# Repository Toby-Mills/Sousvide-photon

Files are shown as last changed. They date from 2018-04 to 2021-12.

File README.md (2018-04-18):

# photon

A Particle project named photon

## Welcome to your project!

Every new Particle project is composed of 3 important elements that you'll see have been created in your project directory for photon.

#### ```/src``` folder:  
This is the source folder that contains the firmware files for your project. It should *not* be renamed. 
Anything that is in this folder when you compile your project will be sent to our compile service and compiled into a firmware binary for the Particle device that you have targeted.

If your application contains multiple files, they should all be included in the `src` folder. If your firmware depends on Particle libraries, those dependencies are specified in the `project.properties` file referenced below.

#### ```.ino``` file:
This file is the firmware that will run as the primary application on your Particle device. It contains a `setup()` and `loop()` function, and can be written in Wiring or C/C++. For more information about using the Particle firmware API to create firmware for your Particle device, refer to the [Firmware Reference](https://docs.particle.io/reference/firmware/) section of the Particle documentation.

#### ```project.properties``` file:  
This is the file that specifies the name and version number of the libraries that your project depends on. Dependencies are added automatically to your `project.properties` file when you add a library to a project using the `particle library add` command in the CLI or add a library in the Desktop IDE.

## Adding additional files to your project

#### Projects with multiple sources
If you would like add additional files to your application, they should be added to the `/src` folder. All files in the `/src` folder will be sent to the Particle Cloud to produce a compiled binary.

#### Projects with external libraries
If your project includes a library that has not been registered in the Particle libraries system, you should create a new folder named `/lib/<libraryname>/src` under `/<project dir>` and add the `.h` and `.cpp` files for your library there. All contents of the `/lib` folder and subfolders will also be sent to the Cloud for compilation.

## Compiling your project

When you're ready to compile your project, make sure you have the correct Particle device target selected and run `particle compile <platform>` in the CLI or click the Compile button in the Desktop IDE. The following files in your project folder will be sent to the compile service:

- Everything in the `/src` folder, including your `.ino` application file
- The `project.properties` file for your project
- Any libraries stored under `lib/<libraryname>/src`

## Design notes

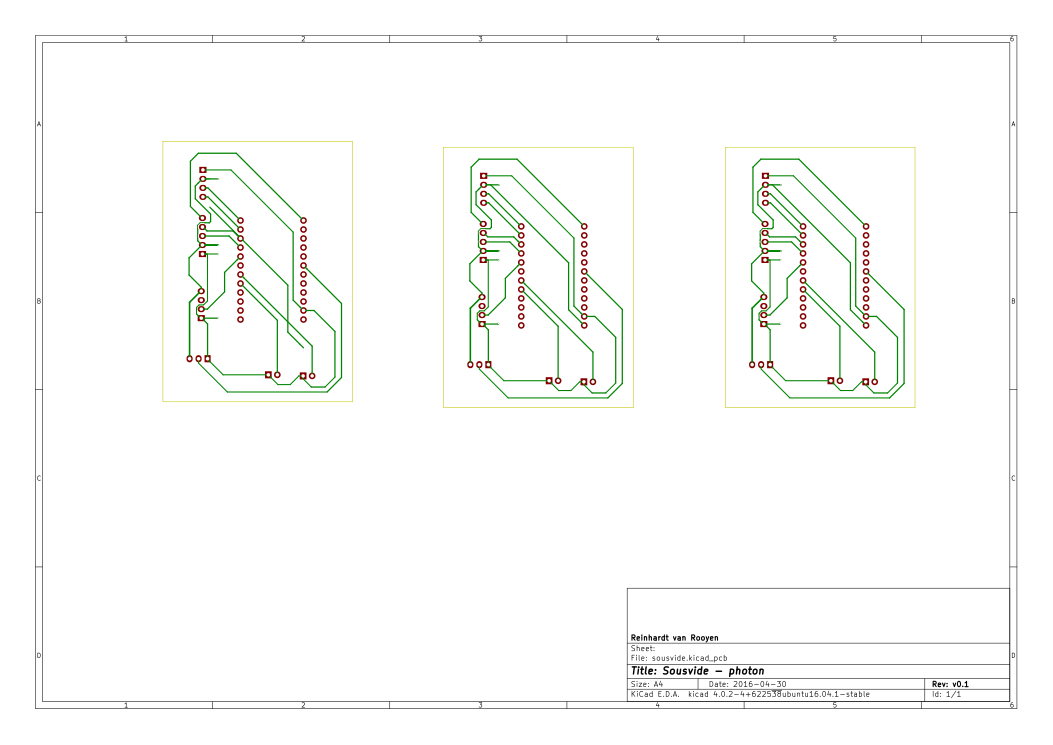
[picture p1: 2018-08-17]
hardware/sousvide-B.Cu-3.png

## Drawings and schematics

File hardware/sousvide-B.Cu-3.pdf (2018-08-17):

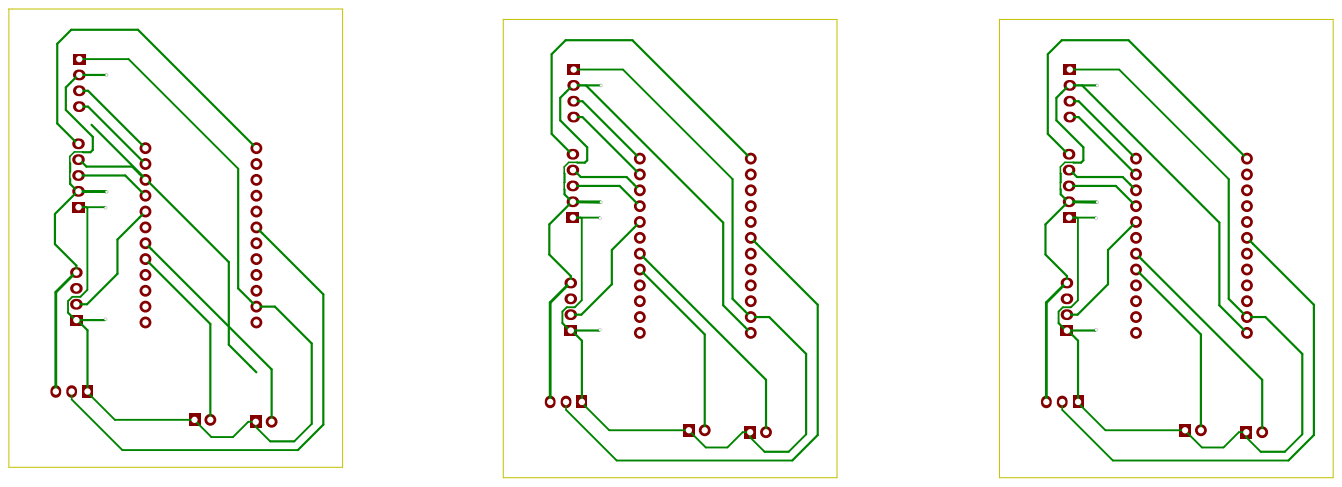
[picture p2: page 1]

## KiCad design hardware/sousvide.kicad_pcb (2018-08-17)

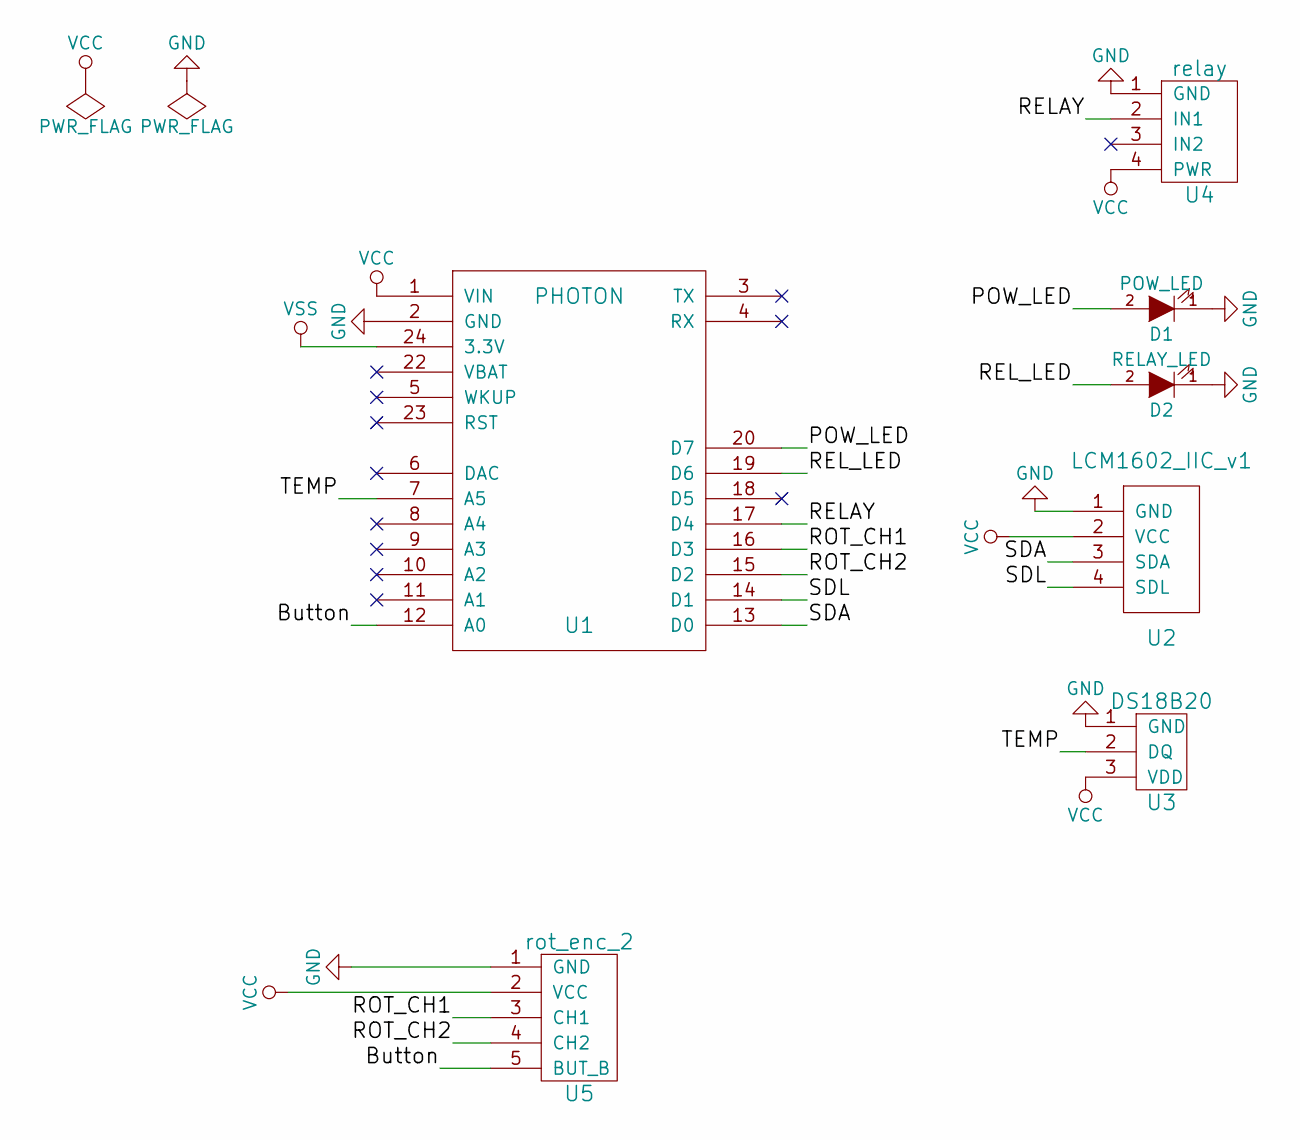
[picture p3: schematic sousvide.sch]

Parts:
D1: POW_LED; LED-5MM
D2: RELAY_LED; LED-5MM
U1: PHOTON; photon
U2: LCM1602_IIC_v1; Pin_Header_Straight_1x04
U3: DS18B20; Pin_Header_Straight_1x03
U4: relay; Pin_Header_Straight_1x04
U5: rot_enc_2; Pin_Header_Straight_1x05

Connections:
/Button: U1.12 (A0), U5.5 (BUT_B)
/POW_LED: D1.2 (A), U1.20 (D7)
/RELAY: U1.17 (D4), U4.2 (IN1)
/REL_LED: D2.2 (A), U1.19 (D6)
/ROT_CH1: U1.16 (D3), U5.3 (CH1)
/ROT_CH2: U1.15 (D2), U5.4 (CH2)
/SDA: U1.13 (D0), U2.3 (SDA)
/SDL: U1.14 (D1), U2.4 (SDL)
/TEMP: U1.7 (A5), U3.2 (DQ)
GND: D1.1 (K), D2.1 (K), U1.2 (GND), U2.1 (GND), U3.1 (GND), U4.1 (GND), U5.1 (GND)
VCC: U1.1 (VIN), U2.2 (VCC), U3.3 (VDD), U4.4 (PWR), U5.2 (VCC)
VSS: U1.24 (3.3V)

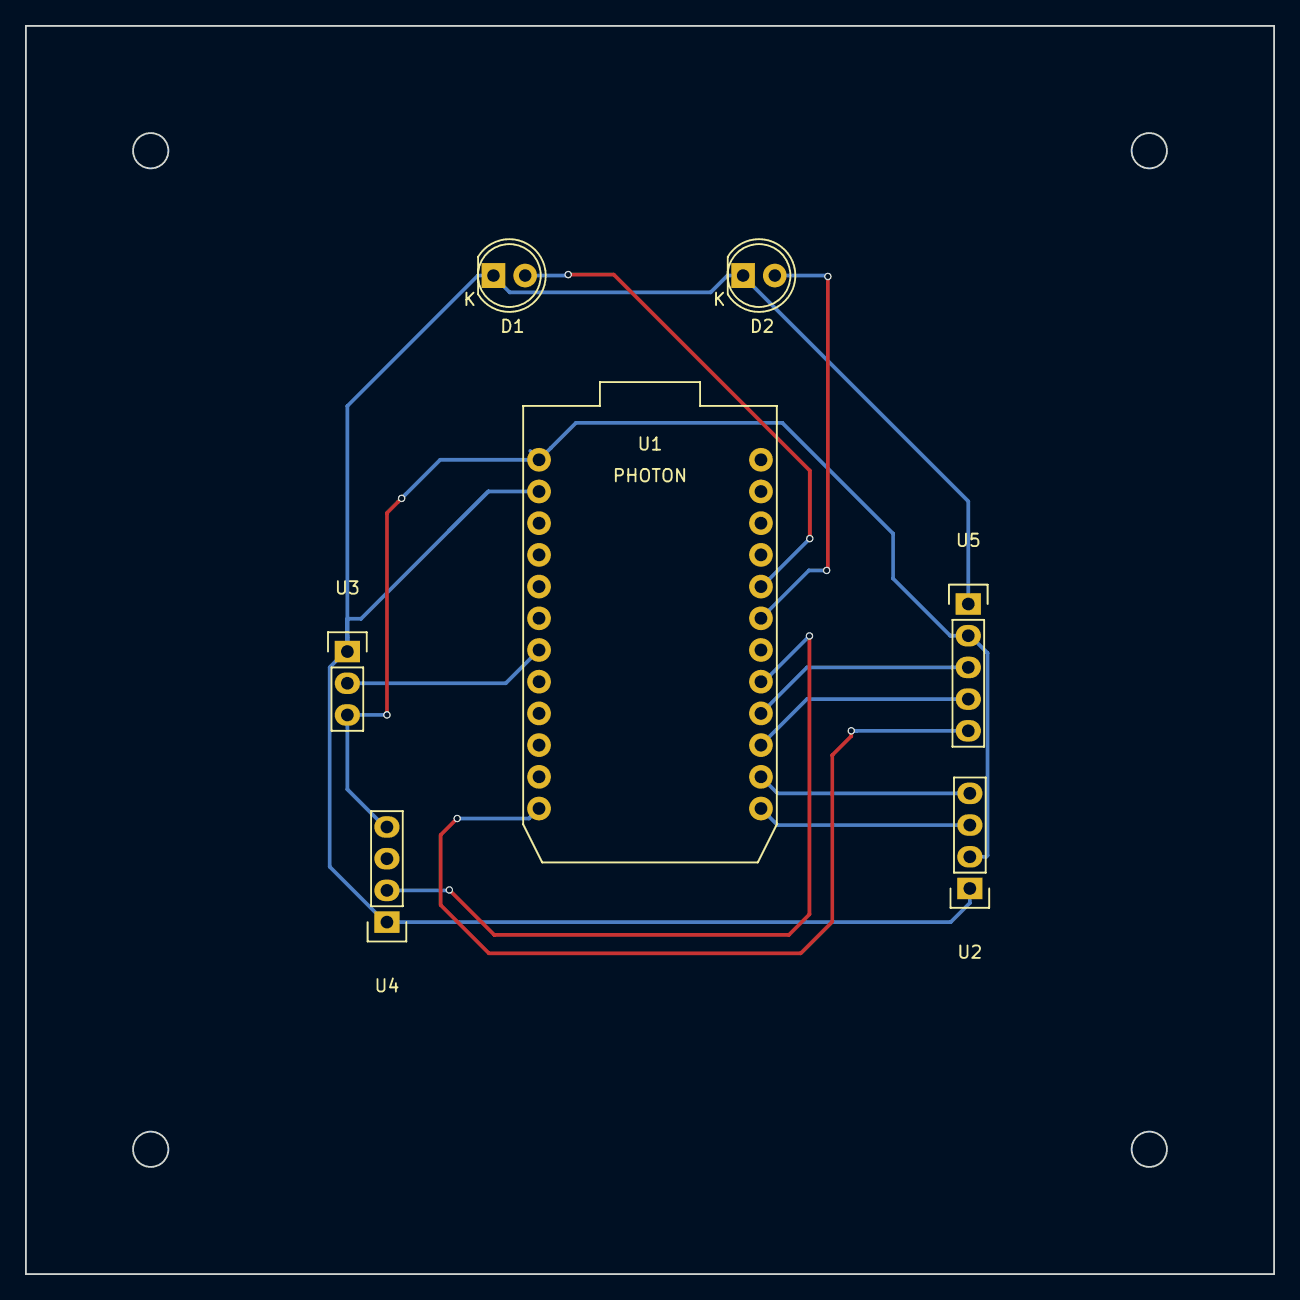
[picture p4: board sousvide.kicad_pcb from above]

Board: 2 copper layers, 100.0 x 100.0 mm, 7 parts (0 on the bottom side), 11 nets.

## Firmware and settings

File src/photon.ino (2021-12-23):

//--------------------------------------------------------------
// Included libraries
//--------------------------------------------------------------
#include "config.h" //add your own config.h with: char const blynkToken[] = "your-blynk-token-here"
#include "OneWire.h"
#include "spark-dallas-temperature/spark-dallas-temperature.h"
#include "LiquidCrystal_I2C_Spark.h"
#include <math.h>
#include <string.h>
#include <Encoder.h>
#include "MQTT.h"

//--------------------------------------------------------------
// Variables
//--------------------------------------------------------------
SYSTEM_THREAD(ENABLED); //enables system functions to happen in a separate thread from the application setup and loop
//this includes connecting to the network and the cloud

char *sourceCode = "https://github.com/Toby-Mills/Sousvide-photon";

int defaultTargetTemperature = 60;
double targetTemperature;
double currentTemperature = 0; //current temperature

char *messageCurrentTemp = "Current";
char *messageTargetTemp = "Target";
char *messageSetTemp = "Set Target";

unsigned long lastSensorReading = 0; //time of last sensor reading
unsigned long sensorReadingDelay = 1000; //minimum milliseconds between processing successive temperature readings

unsigned long lastRelayCommand = 0; //time of last command to relay
unsigned long relayCommandDelay = 5000; //minimum milliseconds between succesive commands to relay

unsigned long lastScreenRedraw = 0; //time of last screen redraw
unsigned long screenRedrawDelay = 600000; //minimum milliseconds between successive redraws of screen

long encoderNewPosition = -999;
long encoderOldPosition  = -999;

int buttonReading = 0;
bool buttonClick = false;

bool setTempMode = false;
int newTargetTemp =  0;

bool timerStarted = false;
bool timerEnded = false;
unsigned long timerLength = 0;
unsigned long timerStartTime = 0;
unsigned long lastTimerUpdate = 0; //time of last timer update
unsigned long timerUpdateDelay = 1000; //minimum milliseconds between succesive timer updates

unsigned long lastStatusPublish = 0; //time of last time the status was published
unsigned long StatusPublishDelay = 10000; //minimum milliseconds between publishing status updates
//--------------------------------------------------------------
//Pin declarations
//--------------------------------------------------------------
int ONE_WIRE_BUS = A5;
int relayPin = D4;
int encoderPin1 = D3;
int encoderPin2 = D2;
int ledPowerPin = D7;
int ledRelayPin = D6;
int buttonPin = A0;

//--------------------------------------------------------------
// MQTT
//--------------------------------------------------------------
bool mqttConnected = false;
byte mqttServer[] = {192, 168, 68, 135};
MQTT mqttClient(mqttServer, 1883, mqttCallback);
char *mqttTopic_cmnd_set_target = "cmnd/sous_vide/target";
char *mqttTopic_stat = "stat/sous_vide";
// char *mqttTopic_cmnd_start_timer = "cmnd/sous_vide/timer";
// char *mqttTopic_cmnd_stop = "cmnd/sous_vide/stop";

//--------------------------------------------------------------
// Initialize libraries
//--------------------------------------------------------------
LiquidCrystal_I2C *lcd;
 // Setup a oneWire instance to communicate with any OneWire devices
OneWire oneWire(ONE_WIRE_BUS);
// Pass our oneWire reference to Dallas Temperature.
DallasTemperature sensors(&oneWire);
DeviceAddress thermometer1 = { 0x28, 0x94, 0xE2, 0xDF, 0x02, 0x00, 0x00, 0xFE };
Encoder encoder(encoderPin1, encoderPin2);

//--------------------------------------------------------------
// Setup
//--------------------------------------------------------------

// setup() runs once, when the device is first turned on.
void setup() {
  Particle.variable("sourceCode", sourceCode, STRING);
  Particle.variable("currentTemp", currentTemperature);
  Particle.variable("targetTemp", targetTemperature);
  Particle.function("setTemp", setDesiredTemperature_Cloud);
  Particle.variable("buttonRead", buttonReading);
  Particle.variable("buttonClick", buttonClick);
  Particle.function("setTimer", setTimer_Cloud);
  Particle.variable("timerLength", timerLength);

  // Set pin modes
  pinMode(ONE_WIRE_BUS, INPUT);
  pinMode(relayPin, OUTPUT);
  pinMode(ledPowerPin, OUTPUT);
  pinMode(ledRelayPin, OUTPUT);
  pinMode(buttonPin, INPUT_PULLDOWN);

  digitalWrite(ledPowerPin, HIGH);

  loadDesiredTemperature();

  //initialize the temperature sensor
  sensors.begin();
  // set the resolution to 10 bit (good enough?)
  sensors.setResolution(thermometer1, 12);

  // initialize the lcd
  initializeDisplay();

  //initialize rotary encoder
  encoderOldPosition = encoder.read();

}

//--------------------------------------------------------------
// Loop
//--------------------------------------------------------------
void loop() {

  if (!mqttClient.isConnected())
  {
    mqttConnected = false;
    mqttClient.connect("sousVide");
  }
  else
  {
    if (!mqttConnected)
    {
      mqttConnected = true;
      mqttClient.publish("stat/sousVide", "connected");
      Particle.publish("Log Event", "mqtt connected");
      mqttClient.subscribe(mqttTopic_cmnd_set_target);
      // mqttClient.subscribe(mqttTopic_cmnd_start);
      // mqttClient.subscribe(mqttTopic_cmnd_start_timer);
      // mqttClient.subscribe(mqttTopic_cmnd_stop);
    }
    mqttClient.loop();
  }

  if (buttonClicked()){
    if(setTempMode == false){
        newTargetTemp = targetTemperature;
        setTempMode = true;
        redrawScreen();
    }else{
      setDesiredTemperature(newTargetTemp);
      setTempMode = false;
      redrawScreen();
    }
  }

  if(setTempMode==true){
    int encoderDirection = readEncoderDirection();
    newTargetTemp = newTargetTemp + encoderDirection;
    writeScreenBottomValue(newTargetTemp);
  }

  //process a sensor reading if the minimum time has elapsed
  if ( millis() - lastSensorReading >= sensorReadingDelay) {
    float sensorTemperature;
    sensorTemperature = getSensorTemperature();
    if(sensorTemperature > -127){
      currentTemperature = sensorTemperature;
    }

    //record time of last sensor reading
    lastSensorReading = millis();

    //write the current temperature to the screen
    writeScreenTopValue(currentTemperature);
  }

  //publish a status update if needed
  if ( millis() - lastStatusPublish >= StatusPublishDelay) {
      char msg[50];
      sprintf(msg, "{\"currentTemp\": %0.2f, \"targetTemp\": %0.2f}", currentTemperature, targetTemperature);
      mqttClient.publish(mqttTopic_stat, msg);
      lastStatusPublish = millis();
  }

  switchRelay();
  updateTimer();

  //redraw the screen if the minimum time has elapsed
  if (( millis()  - lastScreenRedraw >= screenRedrawDelay) ||(lastScreenRedraw == 0)){
    redrawScreen();
    //record time of latest screen redraw
    lastScreenRedraw = millis();
  }
//end of loop
}

//---------------------------------------------------------------
// Functions
//---------------------------------------------------------------

void publishMessage(String name, String message, int value)
{
  char msg[50];
  sprintf(msg, message.c_str(), value);
  Particle.publish(name, msg, 600, PRIVATE);
}

void updateTimer(){
  unsigned long timeRemaining;

  if (( millis() - lastTimerUpdate >= timerUpdateDelay) || (lastTimerUpdate == 0)) {
    if(timerLength > 0){
      if(timerStarted == false){
        if(currentTemperature > targetTemperature){
          timerStarted = true;
          timerStartTime = millis();
        }
      }else{
        if(millis() - timerStartTime > timerLength){
          timerEnded = true;
        }else{
          timeRemaining = calculateTimeRemaining();
        }
      }
    }
    //record time of latest timer update
    lastTimerUpdate = millis();
  }
  
}

unsigned long calculateTimeRemaining(){
  unsigned long millisRemaining;

  millisRemaining = timerLength- (millis() - timerStartTime);
  return millisRemaining;
}

String formatTime(unsigned long millis){
  char returnValue[8];
  unsigned long workingMillis;
  int hours;
  int minutes;
  int seconds;

  workingMillis = millis;
  hours = workingMillis / (1000*60*60);
  workingMillis = workingMillis - (hours*1000*60*60);
  minutes = workingMillis / (1000*60);
  workingMillis = workingMillis - (minutes*1000*60);
  seconds = workingMillis / 1000;

  sprintf(returnValue,"%02d:%02d:%02d", hours, minutes, seconds);
  return returnValue;
}

//Method to switch the relay on or off as needed
void switchRelay(){
  //set the relay if the minimum time has elapsed
  if (( millis() - lastRelayCommand >= relayCommandDelay) || (lastRelayCommand == 0)) {
    //if  more than the buffer amount above the desired temperature, switch the relay off
    if ((currentTemperature +0.2 < targetTemperature) && timerEnded == false) {
      digitalWrite(relayPin, LOW);
      digitalWrite(ledRelayPin, HIGH);
    } else {
      digitalWrite(relayPin, HIGH);
      digitalWrite(ledRelayPin, LOW);
    }
    //record time of latest command to relay
    lastRelayCommand  = millis();
  }
}

//Redraw all screen elements
void redrawScreen(){
  //clear the screen and rewrite the various text elements
  lcd->clear();
  writeScreenTopMessage(messageCurrentTemp);
  writeScreenTopValue(currentTemperature);
  if(setTempMode==false){
    writeScreenBottomMessage(messageTargetTemp);
    writeScreenBottomValue(targetTemperature);
  }else{
    writeScreenBottomMessage(messageSetTemp);
    writeScreenBottomValue(newTargetTemp);
  }

}
//Method to indicate user click of button
bool buttonClicked() {

    buttonReading = analogRead(A0);
    if (buttonReading  > 4000){
      if( buttonClick == false){
        buttonClick = true;
        return(true);
      }
    }else{
      buttonClick = false;
    }
    return(false);
}

// Method to set the desired temperature
int setDesiredTemperature_Cloud(String temp) {
  setDesiredTemperature(temp.toFloat());
  return targetTemperature;
}

void setDesiredTemperature(int temperature){
  targetTemperature = temperature;
  EEPROM.put(10, targetTemperature);
  writeScreenBottomValue(targetTemperature);
}

int setTimer_Cloud(String timerMinutes){
  setTimer(timerMinutes.toInt()*60*1000);
  return timerMinutes.toInt();
}

void setTimer(unsigned long timerMillis){
  timerStarted = false;
  timerEnded = false;
  timerStartTime = 0;
  timerLength = timerMillis;
}

void loadDesiredTemperature(){
  // Load the desired temp from storage if available, otherwise use the default
  EEPROM.get(10,targetTemperature);
  if (targetTemperature == 0xFFFF) {
    // Stored memory is empty, so set it to default temp
    targetTemperature = defaultTargetTemperature;
    // write the desired temp to stored memory for next time
    EEPROM.put(10, defaultTargetTemperature);
  }
}

//method to initialize the lcd
void initializeDisplay(){
  //initialize the display
  lcd = new LiquidCrystal_I2C(0x27, 16 , 2);
  lcd->init();
  lcd->backlight();
  lcd->clear();
}

// Method to read temperature
float getSensorTemperature(){
    sensors.requestTemperatures();
    float tempC = sensors.getTempCByIndex(0);
    return tempC;
}

// Method to write to top line of lcd
void writeScreenTopMessage(char* message){
  lcd->setCursor(0,0);
  lcd->print(message);
}

// Method to write current temperature to the lcd
void writeScreenTopValue(double value){
  lcd->setCursor(11,0);
  lcd->print(value);
}

//Method to write to bottom line of lcd
void writeScreenBottomMessage(char* message){
  lcd->setCursor(0,1);
  lcd->print(message);
}

//Method to write the desired temperature to the lcd
void writeScreenBottomValue(double  value){
  lcd->setCursor(11,1);
  lcd->print(value);
}

int readEncoderDirection(){
  encoderNewPosition = encoder.read();
  float returnValue = 0.25 * (encoderNewPosition - encoderOldPosition);
  encoderOldPosition = encoderNewPosition;
  return round(returnValue);
}

// recieve mqtt message
void mqttCallback(char *topic, byte *payload, unsigned int length)
{
  publishMessage("Log Event", "mqtt message received", 0);
  publishMessage("Log Event", topic, 0);

  char value[length + 1];
  memcpy(value, payload, length);
  value[length] = NULL;

  if (strcmp(topic, mqttTopic_cmnd_set_target) == 0)
  {
    setDesiredTemperature_Cloud(value);
  }
}

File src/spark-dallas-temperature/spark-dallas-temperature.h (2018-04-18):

#ifndef DallasTemperature_h
#define DallasTemperature_h

#define DALLASTEMPLIBVERSION "3.7.2"

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
// set to true to include code for new and delete operators
#ifndef REQUIRESNEW
#define REQUIRESNEW false
#endif

// set to true to include code implementing alarm search functions
#ifndef REQUIRESALARMS
#define REQUIRESALARMS true
#endif

#include <inttypes.h>


    #include "application.h"
    #include "OneWire.h"



// Model IDs
#define DS18S20MODEL 0x10  // also DS1820
#define DS18B20MODEL 0x28
#define DS1822MODEL  0x22
#define DS1825MODEL  0x3B

// OneWire commands
#define STARTCONVO      0x44  // Tells device to take a temperature reading and put it on the scratchpad
#define COPYSCRATCH     0x48  // Copy EEPROM
#define READSCRATCH     0xBE  // Read EEPROM
#define WRITESCRATCH    0x4E  // Write to EEPROM
#define RECALLSCRATCH   0xB8  // Reload from last known
#define READPOWERSUPPLY 0xB4  // Determine if device needs parasite power
#define ALARMSEARCH     0xEC  // Query bus for devices with an alarm condition

// Scratchpad locations
#define TEMP_LSB        0
#define TEMP_MSB        1
#define HIGH_ALARM_TEMP 2
#define LOW_ALARM_TEMP  3
#define CONFIGURATION   4
#define INTERNAL_BYTE   5
#define COUNT_REMAIN    6
#define COUNT_PER_C     7
#define SCRATCHPAD_CRC  8

// Device resolution
#define TEMP_9_BIT  0x1F //  9 bit
#define TEMP_10_BIT 0x3F // 10 bit
#define TEMP_11_BIT 0x5F // 11 bit
#define TEMP_12_BIT 0x7F // 12 bit

// Error Codes
#define DEVICE_DISCONNECTED_C -127
#define DEVICE_DISCONNECTED_F -196.6
#define DEVICE_DISCONNECTED_RAW -2032

typedef uint8_t DeviceAddress[8];

class DallasTemperature
{
  public:

  DallasTemperature(OneWire*);

  // initialise bus
  void begin(void);

  // returns the number of devices found on the bus
  uint8_t getDeviceCount(void);

  // returns true if address is valid
  bool validAddress(const uint8_t*);

  // finds an address at a given index on the bus
  bool getAddress(uint8_t*, uint8_t);

  // attempt to determine if the device at the given address is connected to the bus
  bool isConnected(const uint8_t*);

  // attempt to determine if the device at the given address is connected to the bus
  // also allows for updating the read scratchpad
  bool isConnected(const uint8_t*, uint8_t*);

  // read device's scratchpad
  void readScratchPad(const uint8_t*, uint8_t*);

  // write device's scratchpad
  void writeScratchPad(const uint8_t*, const uint8_t*);

  // read device's power requirements
  bool readPowerSupply(const uint8_t*);

  // get global resolution
  uint8_t getResolution();

  // set global resolution to 9, 10, 11, or 12 bits
  void setResolution(uint8_t);

  // returns the device resolution: 9, 10, 11, or 12 bits
  uint8_t getResolution(const uint8_t*);

  // set resolution of a device to 9, 10, 11, or 12 bits
  bool setResolution(const uint8_t*, uint8_t);

  // sets/gets the waitForConversion flag
  void setWaitForConversion(bool);
  bool getWaitForConversion(void);

  // sets/gets the checkForConversion flag
  void setCheckForConversion(bool);
  bool getCheckForConversion(void);

  // sends command for all devices on the bus to perform a temperature conversion
  void requestTemperatures(void);

  // sends command for one device to perform a temperature conversion by address
  bool requestTemperaturesByAddress(const uint8_t*);

  // sends command for one device to perform a temperature conversion by index
  bool requestTemperaturesByIndex(uint8_t);

  // returns temperature raw value (12 bit integer of 1/16 degrees C)
  int16_t getTemp(const uint8_t*);

  // returns temperature in degrees C
  float getTempC(const uint8_t*);

  // returns temperature in degrees F
  float getTempF(const uint8_t*);

  // Get temperature for device index (slow)
  float getTempCByIndex(uint8_t);

  // Get temperature for device index (slow)
  float getTempFByIndex(uint8_t);

  // returns true if the bus requires parasite power
  bool isParasitePowerMode(void);

  bool isConversionAvailable(const uint8_t*);

  #if REQUIRESALARMS

  typedef void AlarmHandler(const uint8_t*);

  // sets the high alarm temperature for a device
  // accepts a char.  valid range is -55C - 125C
  void setHighAlarmTemp(const uint8_t*, char);

  // sets the low alarm temperature for a device
  // accepts a char.  valid range is -55C - 125C
  void setLowAlarmTemp(const uint8_t*, char);

  // returns a signed char with the current high alarm temperature for a device
  // in the range -55C - 125C
  char getHighAlarmTemp(const uint8_t*);

  // returns a signed char with the current low alarm temperature for a device
  // in the range -55C - 125C
  char getLowAlarmTemp(const uint8_t*);

  // resets internal variables used for the alarm search
  void resetAlarmSearch(void);

  // search the wire for devices with active alarms
  bool alarmSearch(uint8_t*);

  // returns true if ia specific device has an alarm
  bool hasAlarm(const uint8_t*);

  // returns true if any device is reporting an alarm on the bus
  bool hasAlarm(void);

  // runs the alarm handler for all devices returned by alarmSearch()
  void processAlarms(void);

  // sets the alarm handler
  void setAlarmHandler(const AlarmHandler *);

  // The default alarm handler
  static void defaultAlarmHandler(const uint8_t*);

  #endif

  // convert from Celsius to Fahrenheit
  static float toFahrenheit(float);

  // convert from Fahrenheit to Celsius
  static float toCelsius(float);

  // convert from raw to Celsius
  static float rawToCelsius(int16_t);

  // convert from raw to Fahrenheit
  static float rawToFahrenheit(int16_t);

  #if REQUIRESNEW

  // initialize memory area
  void* operator new (unsigned int);

  // delete memory reference
  void operator delete(void*);

  #endif

  private:
  typedef uint8_t ScratchPad[9];

  // parasite power on or off
  bool parasite;

  // used to determine the delay amount needed to allow for the
  // temperature conversion to take place
  uint8_t bitResolution;

  // used to requestTemperature with or without delay
  bool waitForConversion;

  // used to requestTemperature to dynamically check if a conversion is complete
  bool checkForConversion;

  // count of devices on the bus
  uint8_t devices;

  // Take a pointer to one wire instance
  OneWire* _wire;

  // reads scratchpad and returns the raw temperature
  int16_t calculateTemperature(const uint8_t*, uint8_t*);

  int16_t millisToWaitForConversion(uint8_t);

  void  blockTillConversionComplete(uint8_t, const uint8_t*);

  #if REQUIRESALARMS

  // required for alarmSearch
  uint8_t alarmSearchAddress[8];
  char alarmSearchJunction;
  uint8_t alarmSearchExhausted;

  // the alarm handler function pointer
  AlarmHandler *_AlarmHandler;

  #endif

};
#endif

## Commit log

2018-05-20 refactored code for setting desired temperature & updating display
2018-07-18 Rotary Encoder adjusts target temp
2018-07-23 Power and Relay LED's added
2018-08-17 Added kicad files for controller board
    [seedstudio.kicad_pcb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]
2018-08-17 moved kicad designs to 'hardware' folder
    [seedstudio.kicad_pcb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]
2018-11-22 Moved encoder reading to in setTemp mode only
2018-11-22 Reduced screen flicker
    Only redraw current temp, rather than whole screen with every new reading
2021-01-31 Changed sensor reading interval to 1 second
2021-02-01 Added support for a Timer function
